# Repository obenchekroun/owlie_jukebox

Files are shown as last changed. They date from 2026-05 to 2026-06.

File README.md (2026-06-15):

🎵 Owlie: A DIY RFID Jukebox

<p align="center">
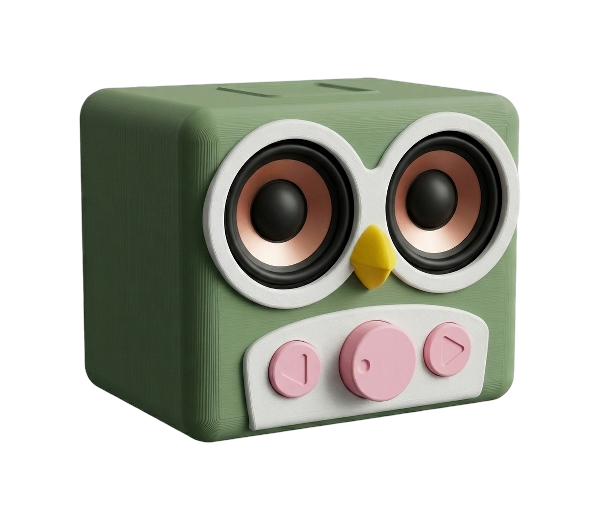
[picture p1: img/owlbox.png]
Jukebox
  
</p>

Owlie is a simple, kid-proof jukebox powered by a **Raspberry Pi 4**, a PN532 RFID reader, and a pair of speakers. This project uses **Raspeberry Pi OS Bookworm 64-bit Lite** for the device firmware, **Phoeniebox** for playback, orchestration and a user-friendly interface.

##  Features

-   **Tap-to-Play:** Present an RFID tag to start playing a playlist.
-   **Auto-Pause:** Remove the tag, and the music pauses.
-   **Smart Resume:** Present the same tag to resume, or a new tag to play new media.
-   **Tactile Controls:** A rotary encoder controls volume, and buttons handle previous/next track.
-   **Wi-Fi Speaker:** Can also be used as a standard Wi-Fi speaker.

## Acknowledgements

-   [Phoniebox](https://phoniebox.de/index-en.html)
-   [Owlbox](https://github.com/XtracT/rfid_jukebox)

---

## Hardware & Assembly

For detailed hardware, assembly, and 3D printing instructions, please see the **[Hardware Manual](manual.md)**.

The core components are:
-   Raspberry Pi 4/5 or 2W
-   PN532 RFID reader (SPI recommended)
-   [Waveshare WM8960 audio HAT](https://www.waveshare.com/wiki/WM8960_Audio_HAT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) or any other Audio DAC/Amp HAT
-   Rotary encoder :  KY-040
-   2 × momentary buttons
-   Passive speakers + 5V/3A power supply
-   [3D-printed enclosure](https://makerworld.com/en/models/1914879)

## Software Setup Guide

### Prerequisites

Owlie uses [Phoeniebox](https://github.com/miczflor/rpi-jukebox-rfid) as the main software. The Waveshare audio HAT requires waveshare drivers to be installed also. If you use any other Audio DAC/Amp HAT, follow the specific instructions for the drivers install.

### Step 1: Flash Raspberry Pi OS

Flash onto the SD card `Raspberry Pi OS Bookworm 64-bit lite`.
Note that Phoeniebox is not compatible yet with Trixie, and the Waveshare HAT requires 64bit firmware.

### Step 2: Install the audio HAT

1. Plug the WM8960 HAT
2. Install the drivers, following [waveshare instructions](https://www.waveshare.com/wiki/WM8960_Audio_HAT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) :
  - Install the prerequisites
``` bash
sudo apt install git
```
**NB :** do not `sudo apt upgrade`, otherwise you will update the kernel and the standard WM8960 drivers won't work. In that case, rely on the drivers here : [ubopod instructions](https://github.com/ubopod/WM8960-Audio-HAT/tree/master)
  - Install the drivers
``` bash
git clone https://github.com/waveshare/WM8960-Audio-HAT
cd WM8960-Audio-HAT
sudo chmod +x install.sh
sudo ./install.sh 
sudo reboot
```
**NB : ** If you come across the following errors trying to run `aplay` :
```bash
ALSA lib pcm_direct.c:1336:(snd1_pcm_direct_initialize_slave) unable to install hw params
ALSA lib pcm_dmix.c:1011:(snd_pcm_dmix_open) unable to initialize slave
```
try this branch [ubopod instructions](https://github.com/ubopod/WM8960-Audio-HAT/tree/master)

  - Check if the driver is installed
  ```bash
pi@raspberrypi:~ $ sudo dkms status 
wm8960-soundcard, 1.0, 4.19.58-v7l+, armv7l: installed
  ```
  - Check the soundcard : 
  ```bash
pi@raspberrypi:~ $ aplay -l
**** List of PLAYBACK Hardware Devices ****
card 1: wm8960soundcard [wm8960-soundcard], device 0: bcm2835-i2s-wm8960-hifi wm8960-hifi-0 []
  Subdevices: 1/1
  Subdevice #0: subdevice #0
  ```
  - test the sound :
```bash
aplay /usr/share/sounds/alsa/*
```
  - adjust the volume
```bash
sudo alsamixer
```
If WM8960 is not the default sound card, you should press F6 to choose an audio device.

### Step 3: Install Phoenixbox

1.  This project uses Phoenix 2. It should work on Phoeniebox 3 when its full version is released
2.  Follow these [instructions](https://github.com/MiczFlor/RPi-Jukebox-RFID/wiki/INSTALL) for installation
```bash
cd; rm install-jukebox.sh; wget https://raw.githubusercontent.com/MiczFlor/RPi-Jukebox-RFID/master/scripts/installscripts/install-jukebox.sh; chmod +x install-jukebox.sh; ./install-jukebox.sh
```
3. Follow on-screen instructions for full install
  - select the PN532 I2C integration when prompted
  - activate the gpio control when prompted

### Step 4: adjust the soundcard configuration (notably for volume control)

Following these issues [#1217](https://github.com/MiczFlor/RPi-Jukebox-RFID/issues/1217) and [#549](https://github.com/MiczFlor/RPi-Jukebox-RFID/issues/549).
To get the sound card WM8960 correctly working :
1. Adjust the `mpd.conf`configuration 
```bash
sudo nano /etc/mpd.conf
```
2. Look for the àudio_output entry that is not commented out. Comment it out et replace it by :
```bash
audio_output {
        type            "alsa"
        name            "WM8960 HiFi HAT"
        device          "hw:CARD=wm8960soundcard,DEV=0"
        mixer_type      "hardware"
        mixer_device    "hw:CARD=wm8960soundcard"
        mixer_control   "Speaker"
}
```
3. Check alsa config :
Run `amixer -c 1 scontrols` (the WM8960 Hi-Fi HAT is card number 1, use `aplay -l` to get the number). You should end up with a long list of 51 simple mixer controls, including "Playback". If you get this long list, your ALSA setting should be fine.

4. Might need to run `sudo systemctl enable mpd.service` if you get `An error occorured: Execution failed Command: /home/pi/RPi-Jukebox-RFID/scripts/playout_controls.sh -c=volumeup Output: RC: .1`

5. Adjust iFace name : `nano RPi-Jukebox-RFID/settings/Audio_iFace_Name` and change `PCM` to `Speaker`

6. Use `alsamixer` to adjust sound. Switch card using `F6`. If you want to keep settings between reboot :

``` bash
# sudo alsactl store 1 #1 being the card number
sudo alsactl --file=/etc/wm8960-soundcard/wm8960_asound.state  store
```

### Step 5: Setup PN532 RFID reader

These instructions are for the following RFID reader:

<https://shop.pimoroni.com/products/adafruit-pn532-nfc-rfid-controller-shield-for-arduino-extras>

Similar shields/breakout boards, based on the same chip might work, but have not been tested.  

It has been tested with the I2C interface. Using SPI might work as well, but it has not been tested.

1. Connect the PN532 RFID reader to the GPIO pins

    | PN532 | Raspberry Pi | Raspi Pins |
    | ----- | ------------ | ---------- |
    | 5V    | 5V           |     4      |
    | GND   | GND          |     6      |
    | SDA   | GPIO 2 (SDA) |     3      |
    | SCL   | GPIO 3 (SCL) |     5      |

2. Activate the I2C interface of the Raspberry Pi
    - `sudo raspi-config`
    - Select "5 Interfacing Options" -> I2C -> yes
    - or instead of using the UI, here is the CLI command:
        `sudo raspi-config nonint do_i2c 0`

3. Install I2C tools
    - `sudo apt-get install i2c-tools`

4. Check that the reader is found trough I2C
    - check `sudo i2cdetect -y 1`
    - output should look like this:

                 0  1  2  3  4  5  6  7  8  9  a  b  c  d  e  f
            00:          -- -- -- -- -- -- -- -- -- -- -- -- -- 
            10: -- -- -- -- -- -- -- -- -- -- -- -- -- -- -- -- 
            20: -- -- -- -- 24 -- -- -- -- -- -- -- -- -- -- -- 
            30: -- -- -- -- -- -- -- -- -- -- -- -- -- -- -- -- 
            40: -- -- -- -- -- -- -- -- -- -- -- -- -- -- -- -- 
            50: -- -- -- -- -- -- -- -- -- -- -- -- -- -- -- -- 
            60: -- -- -- -- -- -- -- -- -- -- -- -- -- -- -- -- 
            70: -- -- -- -- -- -- -- -- 

    - if the table is empty, try switching I2C off and on again in raspi-config or reboot

5. Configure experimental reader
   - `cd scripts`
   - `cp Reader.py.experimental Reader.py`
   - Run `python3 RegisterDevice.py`
   - Select 2 (PN532)

6. Restart the phoniebox-rfid-reader service
   - `sudo systemctl restart phoniebox-rfid-reader.service`

### Step 6: Configure GPIO actions

1. Create and run the service
  - The service can be activated during installation with the installscript.
  - If the service was not activated during installation, you can alternatively use `sudo install.sh` in `components/gpio_control`.
2. Configure in the file `~/RPi-Jukebox-RFID/settings/gpio_settings.ini`. Refer to [Phoeniebox documentation](https://github.com/MiczFlor/RPi-Jukebox-RFID/blob/develop/components/gpio_control/README.md#rotaryencoder)
3. Use `sudo systemctl restart phoniebox-gpio-control` to activate new settings

Please note that pins are GPIO numbers

#### For the Rotary encoder

```ini
[RotaryVolumeControl]
enabled: True
Type: RotaryEncoder
Pin1: 22
Pin2: 23
timeBase: 0.1
functionCall1: functionCallVolU
functionCall2: functionCallVolD
```
* **enabled**: This needs to be `True` for the rotary encoder to work.
* **Pin1**: GPIO number corresponding to rotary direction "clockwise" ('CLK')
* **Pin2**: GPIO number corresponding to rotary direction "counter clockwise" ('DT')
* **functionCall1: functionCallVolU**: function called for every rotation step corresponding to rotary direction "clockwise" (custom steps as optional argument).
* **functionCall2: functionCallVolD**: function called for every rotation step corresponding to rotary direction "counter clockwise" (custom steps as optional argument).
* **timeBase**: Factor used for calculating the rotation value base on rotation speed, defaults to `0.1`. Use `0` for deactivating rotation speed influence.

and its button

```ini
[PlayPause]
enabled: True
Type: Button
Pin: 27
pull_up_down: pull_up
functionCall: functionCallPlayerPause
```

The corresponding pinout :
```text
  .---------------.                      .---------------.
  |               |                      |               |
  |           CLK |----------------------| GPIO 22       |
  |               |                      |               |
  |           DT  |----------------------| GPIO 23       |
  |               |                      |               |
  |           SW  |----------------------| GPIO 27       |
  |               |                      |               |
  |           +   |----------------------| 3.3V          |
  |               |                      |               |
  |           GND |----------------------| GND           |
  |               |                      |               |
  '---------------'                      '---------------'
       KY-040                                Raspberry
```

#### For the button next and prev song

```ini
[NextSong]
enabled: True
Type:  Button
Pin: 26
pull_up_down: pull_up
functionCall: functionCallPlayerNext

[PrevSong]
enabled: True
Type:  Button
Pin: 6
pull_up_down: pull_up
functionCall: functionCallPlayerPrev
```

Be careful of overlap with the WM8960 HAT if adding other GPIOs. Here is it's full pinout

| Functional Pins | Raspberry Pi Pins (BCM) | Description |
|---|---|---|
| 5V | 5V | Power positive (5V power input) |
| GND | GND | Power Ground |
| SDA | P2/SDA | I2C data input |
| SCL | P3/SCL | I2C clock Input |
| CLK | P18 | I2S bit clock input |
| LRCLK | P19 | I2S frame clock input |
| DAC | P21 | I2S serial data output |
| ADC | P20 | I2S serial data input |
| BUTTON | P17 | Custom buttons |

### Step 7: configure RFID chips, playlists, music through web-interface

1. Connect to the web-interface : `http://owlie.local` // `http://<ip>`
2. you can add music through the web interface or in `~/RPi-Jukebox-RFID/shared/audiofolders`

### Step 8 : assemble the hardware [Hardware Manual](manual.md)

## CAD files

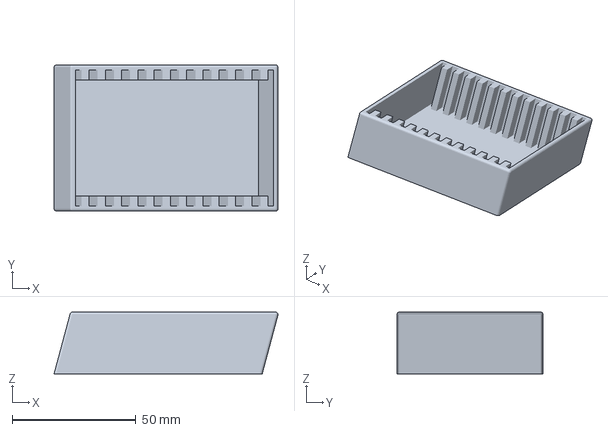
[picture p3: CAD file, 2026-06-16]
Card+Hooder.3mf
90.4 x 59.0 x 25.0 mm

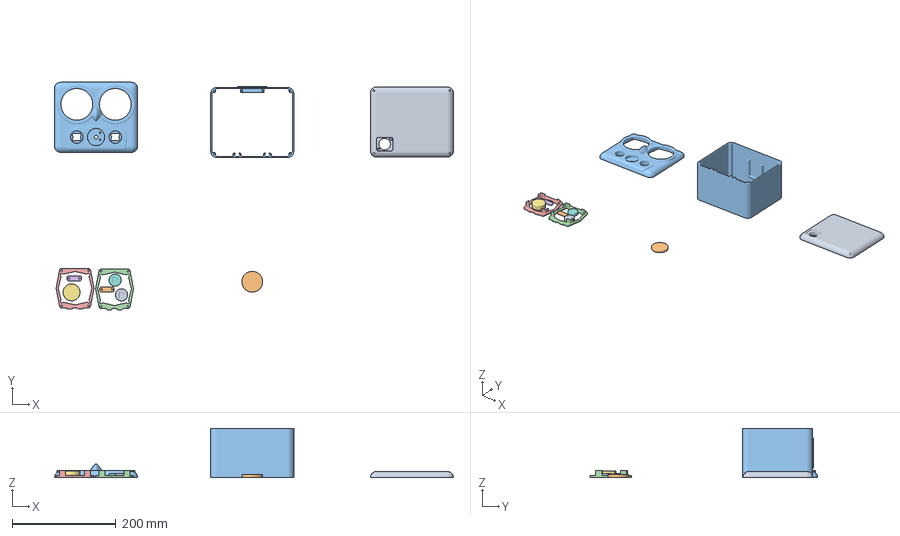
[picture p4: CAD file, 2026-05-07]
owlbox_bambustudio.3mf
767.6 x 437.7 x 95.0 mm
back lid
figure base
faceplate

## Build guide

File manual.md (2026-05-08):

# **Owlie: A DIY RFID Jukebox Guide**

## **1. Project Overview**

Welcome to the Owlie! This is an adorable, 3D-printed speaker designed to be controlled by physical RFID tags. It's a fantastic project for introducing kids to music, stories, and technology in a simple, screen-free, and interactive way.

This enclosure is designed for robustness (toddler-tested!) and flexibility. It can be built using ::

*   **Raspberry Pi Build:** A powerful build using a **Raspberry Pi (Zero, 4, or 5)**, perfect for running the popular **Phoniebox** project.

**Key Features:**

*   **Clean, Screw-Free Front:** The entire assembly is held together from the back.
*   **Internally Braced:** Internal braces prevent the body from flexing or bending.
*   **Tactile Controls:** Uses satisfying mechanical (MX) switches and a rotary encoder.
*   **Magnetic Tag System:** Printable RFID tag bases with embedded magnets snap onto a hidden magnet in the enclosure.

---

## **2. Bill of Materials**

This project requires a mix of 3D printed parts and readily available electronics.

### **2.1 3D Printed Parts**

It is highly recommended to use the print profiles provided in the [Makerworld project repository](https://makerworld.com/fr/models/1914879-owlbox-rfid-tag-speaker-for-kids-phoniebox#profileId-2053948). These profiles are pre-configured with optimal settings and support placements.

### **2.2 Electronics & Hardware**

#### **Core Platform (Choose ONE)**

**Raspberry Pi Build**

*   **Microcontroller:** 1x Raspberry Pi (Zero 2, 4, or 5)
*   **Software:** [Phoniebox Project](https://phoniebox.de/)
*   **Audio:** 1x DAC/Amplifier HAT for the Pi (e.g., HiFiBerry MiniAmp or Waveshare WM8960 HAT). Ensure it can drive two 4 Ohm speakers at 5V.
*   **Internal Power Cable:** 1x USB-C to Micro-USB (for Pi Zero) or USB-C to USB-C (for Pi 4/5) (prefer an angled one).

#### **Common Electronics**

*   **Speakers:** 2x **2.5-inch Full-Range Speaker Drivers**.
    *   *Note: This enclosure is designed for **AIYIMA 2.5-inch drivers** (68x68mm frame). The **4 Ohm** version is highly recommended for a 5V-6V power supply.* (Aliexpress: 1005003690882286) 
*   **RFID Reader:** 1x **PN532** Module (I2C interface recommended for Phoeniebox).
*   **Rotary Encoder:** 1x **KY-040** Module.
*   **Buttons:** 2x **MX-style Mechanical Keyboard Switches** (e.g., Cherry, Gateron).
*   **Panel Connector:** 1x **USB-C Panel Mount**  (Aliexpress: 1005009758437594).
*   **Panel to board connector**  1x **USB-C to USB-C/Micro-USB angled cable **
*   **Power Source:** 1x **5V-6V DC Power Adapter (min. 3A)**. A standard 5V 3A USB-C adapter is a great starting point.
*   **RFID Tags:** **30mm Round RFID Tags** (13.56MHz, e.g., NTAG213/215) (Aliexpress: 1005008672575582, 32861932088)
*   **Magnets:**
    *   **For Tag Base:** 5+ **12mm x 3mm Coin Magnets**.
    *   **For Enclosure:** Any strong magnet (e.g., rectangular). This will be glued inside the enclosure.
*   **Wiring:**
    *   **Speaker Wire:** ~1m of **0.5mm² (approx. 20-21 AWG)** wire.
    *   **Signal Wire:** Assorted **DuPont-style jumper wires** (Female-to-Female, Female-to-Male).

#### **Fasteners & Tools**

*   **Brass Inserts:**
    *   22x **M3x4mm** (Heat-set)
    *   2x **M2.5x3mm** (Heat-set)
*   **Screws:**
    *   4x **M3 x 100mm** (Socket-head) (Aliexpress: 1005005879037174)
    *   12x **M3 x 8mm** (Socket-head)
    *   4x **M3 x 6mm** (Socket-head)
    *   2x **M3 x 6mm (Countersunk)**
    *   2x **M2.5 x 3mm**
*   **Required Tools:**
    *   Soldering Iron & Solder
    *   **Brass Insert Press Tip** for soldering iron
    *   Hex Keys (M3 and M2.5)
    *   Wire Stripper & Cutters
    *   Super glue or hot glue

## **3. Software & Firmware Setup**

Before starting the physical assembly, it is crucial to flash your microcontroller and test the core electronics.

*   **For the Raspberry Pi Build:** Follow the official Phoniebox documentation to install the software on your Pi.

## **4. 3D Printing Guide**

### **Printing the Faceplate**

This is the only part that requires supports. For best results, use PETG as the support interface material, as configured in the provided print profile.

### **Printing the RFID Tag Base**

This part is designed to permanently embed the RFID tag and magnet.

1.  Slice the RFID Tag Base model.
2.  In your slicer, add a **Pause command** at the layer just before the cavities for the tag and magnet are sealed.

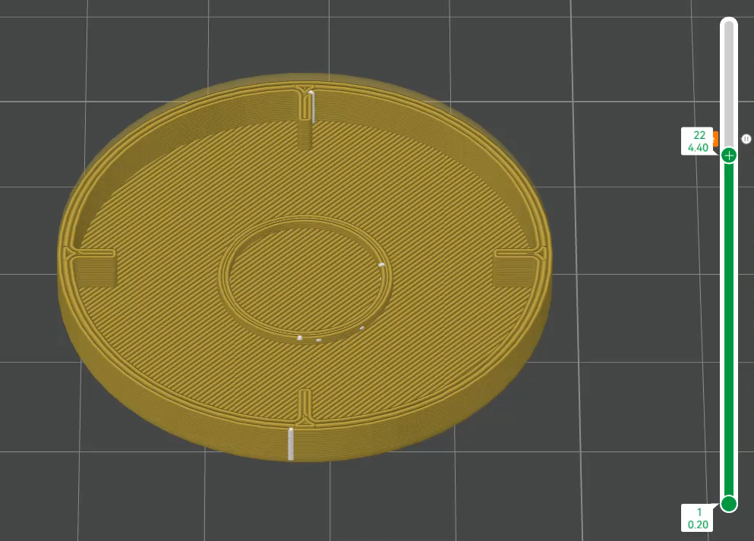
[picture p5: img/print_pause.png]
Print Pause Example
    

3.  Start the print. When it pauses, carefully place one **30mm RFID tag** and one **12x3mm magnet** into their slots.
4.  Resume the print to seal the components inside.

## **5. Hardware Assembly**

### **Step 1: Preparation & Component Assembly**

1.  **Install Brass Inserts:** Carefully use your soldering iron and a press tip to melt all brass inserts into their corresponding holes on the **Faceplate** and **Back Panel**.

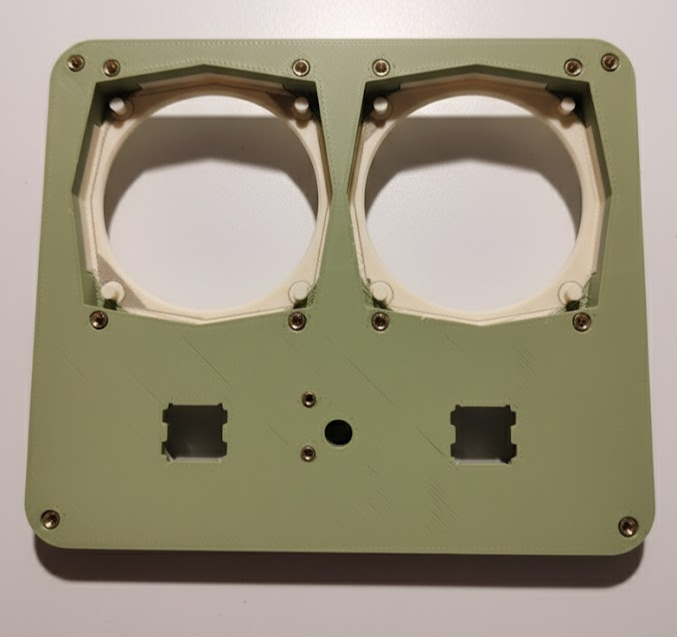
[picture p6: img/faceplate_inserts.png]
Faceplate Inserts
    

2.  **Solder Pin Headers:** For easier assembly, solder pin headers to the Louder ESP32, PN532, MX switches, and rotary encoder. This allows for flexible connections using jumper wires.
3.  **Assemble the Faceplate:**
    *   Mount the **KY-040 encoder** using **2x M2.5x3mm screws**.
    *   Snap the two **MX switches** into their square slots.
    *   Place the two **2.5-inch Speakers** into the recessed "eye" holes.
    *   Secure the speakers with the **Speaker Brackets** using **8x M3x8mm screws**.

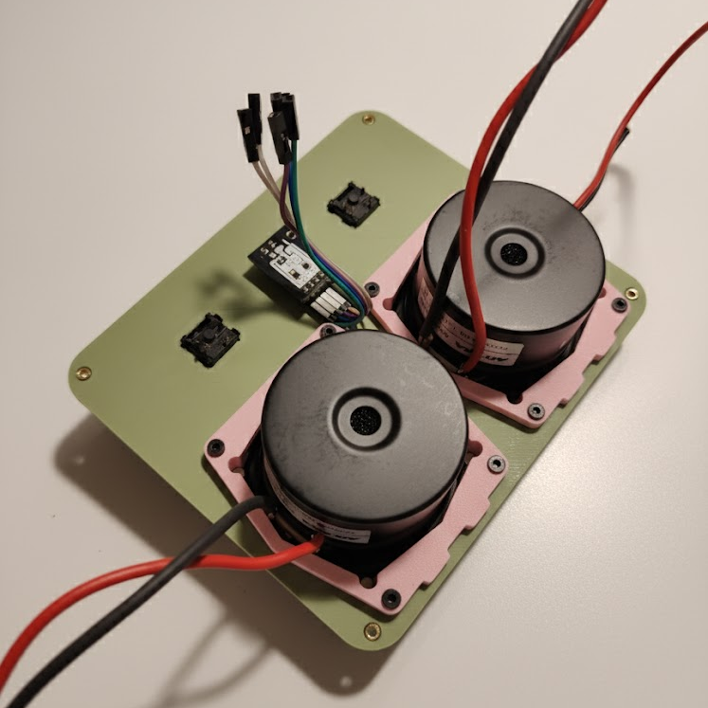
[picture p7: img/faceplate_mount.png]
Faceplate Assembled
    

4.  **Assemble the Back Panel:**
    *   Mount the two **Internal Braces** using **4x M3x8mm screws**.
    *   Mount the **USB-C Panel Mount** using **2x M3x6mm Countersunk screws**.
    *   For Raspberry Pi builds, the mounting will look like this:

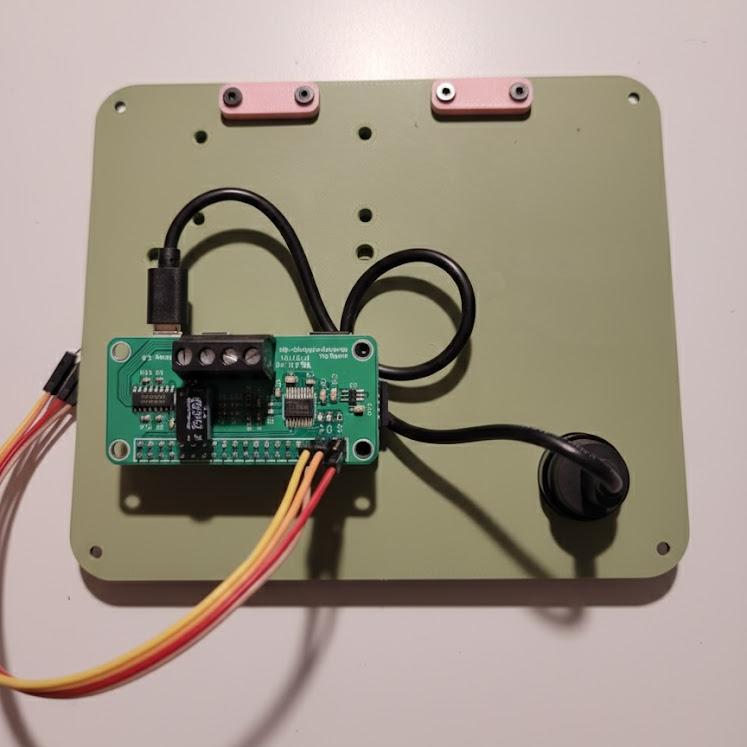
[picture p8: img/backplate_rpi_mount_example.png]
Raspberry Pi Mount Example
    

### **Step 2: Wiring & Connections**

With the components mounted, you can now perform the wiring. It is easier to do this *before* mounting the board, as the pin labels are on the back.

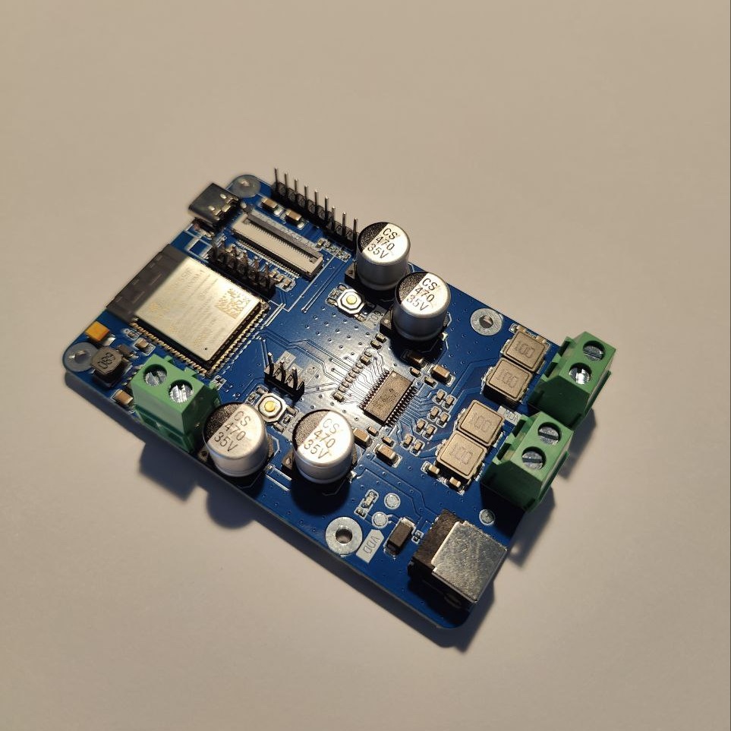
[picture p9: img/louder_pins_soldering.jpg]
Soldering Pins


1.  **Configure PN532 for I2C:** Set the DIP switches on the PN532 board for I2C communication: `[SWITCH 1: ON, SWITCH 2: OFF]`. It's also a good idea to protect the solder points with electrical tape.

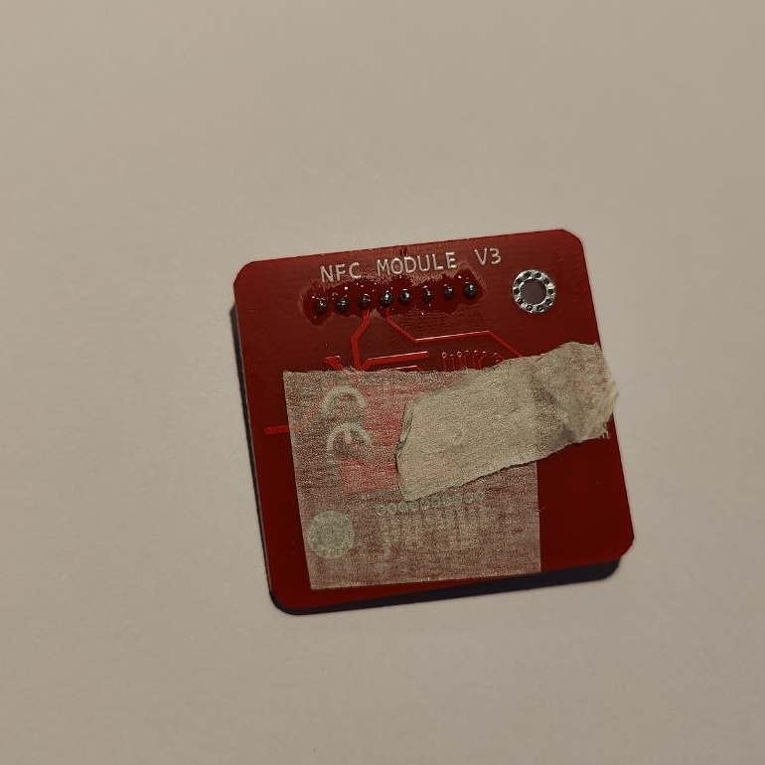
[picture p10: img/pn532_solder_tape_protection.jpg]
PN532 Solder Protection
    
2.  **Connect Components to board:** Refer to the `README.md` file for the exact pinout.

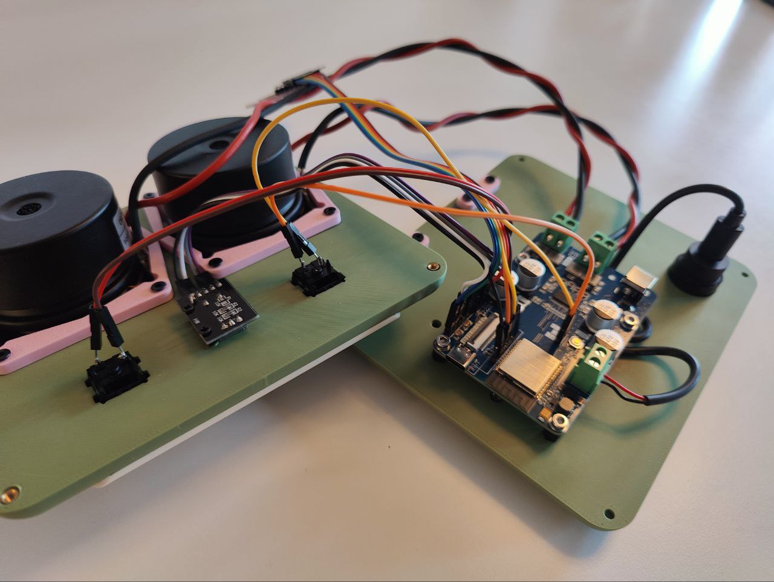
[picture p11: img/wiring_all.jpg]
All components wired


### **Step 3: Final Assembly**

1.  **Mount the board:** Secure the board to the **Back Panel** using **4x M3x6mm screws**.
2.  **Connect Power:** Connect the USB-C pigtail from the panel mount to the screw terminals on the board
3.  **Position the Enclosure:** Slide the main enclosure body over the back of the **Faceplate**. The cables should be long enough to allow both the faceplate and back panel to sit on either side.
4.  **Mount the PN532 & Magnets:**
    *   Secure the **PN532 RFID Reader** to the posts inside the main enclosure. The asymmetrical design ensures it can only be mounted one way.
    *   **Position the Magnets:** This can be tricky. Place three 27x9x2.5mm magnets next to each other. To combine their strength, ensure their magnetic fields point in the same direction. Use tape to hold them in place while you glue them.
    *   **Untested Alternative:** A single, strong 30mm diameter x 3mm high N52 magnet may work and would be easier to install.

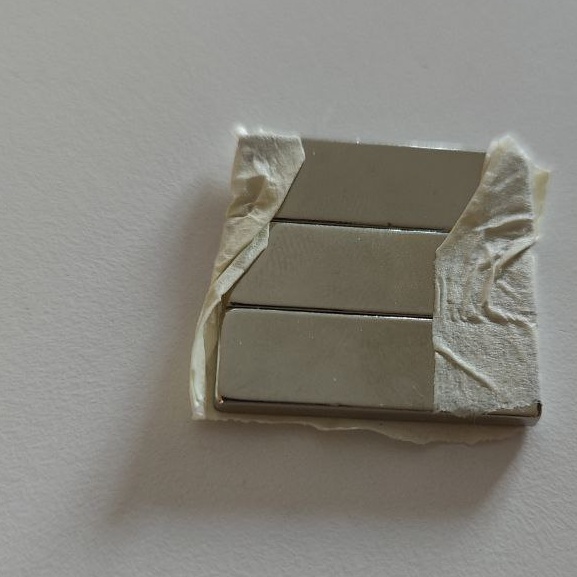
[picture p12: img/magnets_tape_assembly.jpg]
Magnet Tape Assembly
    
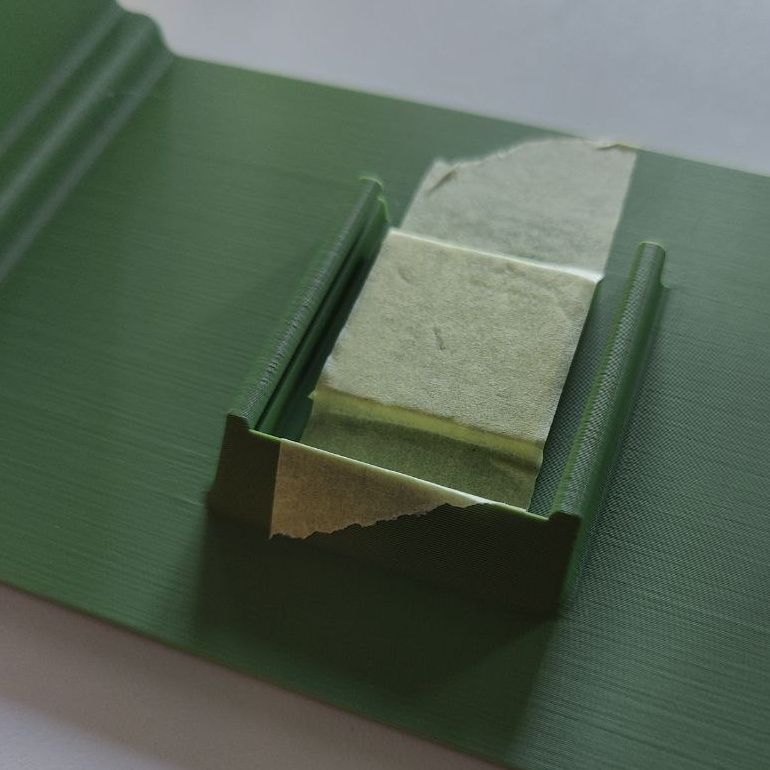
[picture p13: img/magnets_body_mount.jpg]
Magnet Placement
    
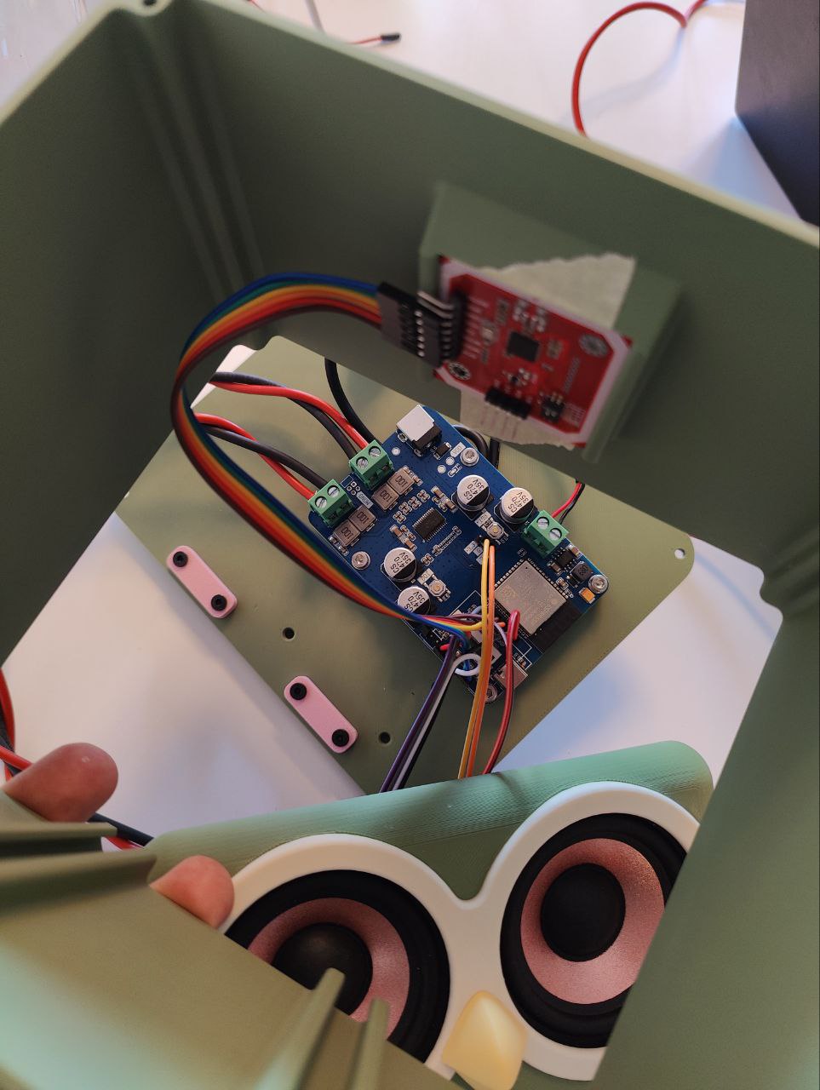
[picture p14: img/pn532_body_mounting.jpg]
PN532 Mount
    

5.  **Secure the Enclosure:** Align the **Back Panel** with the back of the main enclosure. Insert the **4x M3x100mm screws** from the back and tighten evenly until snug. **Do not overtighten!**

## **6. Operation**

1.  **Power On:** Connect your USB-C power source.
2.  **Play Media:** Place an RFID Tag Base—with a figurine glued on top—onto the Owlie. The magnet will hold it in place.

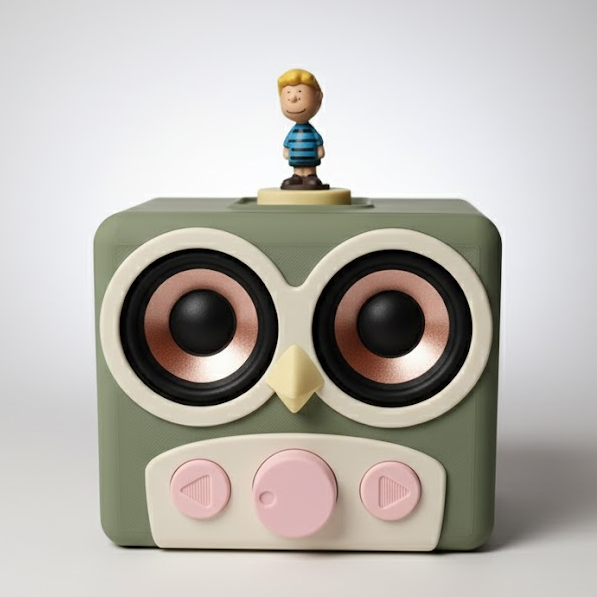
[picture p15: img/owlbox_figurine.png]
Owlie with Figurine
    

3.  **Controls:**
    *   **Knob:** Turn to adjust volume. Press to play/pause.
    *   **Buttons:** Previous/Next track.

Enjoy your new Owlie!

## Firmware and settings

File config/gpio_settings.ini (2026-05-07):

[DEFAULT]
enabled: True
antibouncehack: False

[VolumeControl]
enabled: False
Type: TwoButtonControl
Pin1: 5
Pin2: 6
pull_up_down: pull_up
hold_time: 0.3
hold_mode: Repeat
functionCall1: functionCallVolU
functionCall2: functionCallVolD
functionCallTwoButtons: functionCallVol0
;functionCall1Args: 1
;functionCall2Args: 1
;functionCallTwoButtonsArgs: x

[RotaryVolumeControl]
enabled: True
Type: RotaryEncoder
Pin1: 22
Pin2: 23
timeBase: 0
functionCall1: functionCallVolU
functionCall2: functionCallVolD

[PrevNextControl]
enabled: False
Type: TwoButtonControl
Pin1: 22
Pin2: 23
functionCall1: functionCallPlayerPrev
functionCall2: functionCallPlayerNext
functionCallTwoButtons: None
pull_up_down: pull_up
hold_time: 0.3
hold_mode: None

[PlayPause]
enabled: True
Type: Button
Pin: 27
pull_up_down: pull_up
functionCall: functionCallPlayerPause

[Shutdown]
enabled: False
Type:  Button
Pin: 3
pull_up_down: pull_up
hold_mode: Postpone
hold_time: 2
functionCall: functionCallShutdown

[PauseShutdown]
enabled: False
Type:  Button
Pin: 3
pull_up_down: pull_up
hold_time: 2.0
hold_mode: SecondFunc
functionCall: functionCallPlayerPause
functionCall2: functionCallShutdown

[Volume0]
enabled: False
Type:  Button
Pin: 17
pull_up_down: pull_up
functionCall: functionCallVol0

[VolumeUp]
enabled: False
Type:  Button
Pin: 16
pull_up_down: pull_up
hold_time: 0.3
hold_mode: Repeat
functionCall: functionCallVolU
;functionCallArgs: 1

[VolumeDown]
enabled: False
Type:  Button
Pin: 19
pull_up_down: pull_up
hold_time: 0.3
hold_mode: Repeat
functionCall: functionCallVolD
;functionCallArgs: 1

[NextSong]
enabled: True
Type:  Button
Pin: 26
pull_up_down: pull_up
functionCall: functionCallPlayerNext

[PrevSong]
enabled: True
Type:  Button
Pin: 6
pull_up_down: pull_up
functionCall: functionCallPlayerPrev

[FastForward]
enabled: False
Type:  Button
Pin: 7
pull_up_down: pull_up
functionCall: functionCallPlayerSeekFwd
;functionCallArgs: 10

[Rewind]
enabled: False
Type:  Button
Pin: 8
pull_up_down: pull_up
functionCall: functionCallPlayerSeekBack
;functionCallArgs: 10

[Halt]
enabled: False
Type:  Button
Pin: 25
pull_up_down: pull_up
functionCall: functionCallPlayerPauseForce

[RFIDDevice]
enabled: False
Type: Button
Pin: 21
pull_up_down: pull_up
functionCall: functionCallPlayerStop

[TriggerPlayCard1]
enabled: False
Type: Button
Pin: 4
pull_up_down: pull_up
functionCall: functionCallTriggerPlayCardId
functionCallArgs: 1

[TriggerPlayFolderSomeRelativeFolderName]
enabled: False
Type: Button
Pin: 4
pull_up_down: pull_up
functionCall: functionCallTriggerPlayFolder
functionCallArgs: someRelativeFolderName

[StatusLED]
enabled: False
Type: StatusLED
Pin: 14
